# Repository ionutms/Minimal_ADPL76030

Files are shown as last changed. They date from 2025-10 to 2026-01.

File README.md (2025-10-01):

# Minimal_ADPL76030

## Overview

This repository contains a minimal KiCad design project for the Analog Devices ADPL76030, a synchronous 4-switch buck-boost DC/DC controller. The project includes schematic designs and PCB layout files for implementing this versatile power supply controller.

## Disclaimer

> [!NOTE]
> This project is provided "as is" and without any warranty, express or implied. For more details, please see the [LICENSE](LICENSE) file.

## About the ADPL76030

The ADPL76030 from Analog Devices is a high-efficiency synchronous 4-switch buck-boost DC-to-DC controller. It can regulate output voltage and current from an input voltage that can be above, below, or equal to the output voltage.

Key features include:

- **Wide Input Voltage Range:** 4V to 55V.
- **High Efficiency:** Up to 95% at 1.4 MHz.
- **Spread Spectrum Frequency Modulation:** For low EMI.
- **Fault Protection:** Includes various protection features.
- **Current Monitoring:** Provides current monitoring capabilities.
- **Package:** Available in a 28-lead LFCSP package.

## Project Structure

```
minimal_adpl76030/
├── minimal_adpl76030.kicad_pro       # Project configuration file
├── minimal_adpl76030.kicad_sch       # Main schematic file
├── minimal_adpl76030.kicad_pcb       # PCB layout file
├── fp-lib-table                    # Footprint library table
├── sym-lib-table                   # Symbol library table
├── docs/                           # Documentation files
│   ├── bom/                        # Bill of Materials
│   │   └── minimal_adpl76030_ibom.html # Interactive BOM file
│   ├── pictures/                   # Images and photos
│   │   ├── 1_minimal_adpl76030_side.png
│   │   ├── 2_minimal_adpl76030_top.png
│   │   ├── 3_minimal_adpl76030_bottom.png
│   │   ├── 4_minimal_adpl76030_left.png
│   │   └── 5_minimal_adpl76030_right.png
│   └── schematics/                 # Schematic PDF exports
│       └── minimal_adpl76030_schematics.pdf
└── KiCAD_Symbols_Generator/        # Submodule for symbol generation from CSV data
```

## Project Features

This design provides a minimal implementation of the ADPL76030 with:

- Proper power supply connections
- Buck-boost functionality
- Standard footprint for the 28-pin LFCSP package

## Getting Started

### Prerequisites

- [KiCad EDA](https://www.kicad.org/) version 9.0 or later installed on your system
- Git (for cloning the repository and submodule management)

### Opening the Project

1. **Clone the repository** (including submodules):
   ```bash
   git clone --recursive https://github.com/ionutms/Minimal_ADPL76030.git
   ```
   
   If you've already cloned the repository without submodules, initialize them with:
   ```bash
   git submodule init
   git submodule update
   ```

2. **Open the project in KiCad**:
   - Launch KiCad
   - Click "Open Existing Project"
   - Navigate to the cloned repository folder
   - Select the `minimal_adpl76030.kicad_pro` file

3. **Explore the design**:
   - Open the schematic editor to view the circuit design
   - Open the PCB editor to view the board layout
   - Review the symbol and footprint libraries used in the design

### Project Files

- **Main schematic**: `minimal_adpl76030.kicad_sch` - Contains the primary circuit design with the ADPL76030 and support components
- **PCB layout**: `minimal_adpl76030.kicad_pcb` - Physical board design file with proper component placement
- **Project configuration**: `minimal_adpl76030.kicad_pro` - KiCad project settings

## Dependencies

This project has the following dependencies:

### 1. KiCAD Symbols Generator

This repository uses [KiCAD_Symbols_Generator](https://github.com/ionutms/KiCAD_Symbols_Generator) as a submodule for custom symbol generation.

To initialize the submodule after cloning this repository:

```bash
git submodule update --init --recursive
```

### 2. 3D Models

This project requires the [3D_Models_Vault](https://github.com/ionutms/3D_Models_Vault) repository for 3D models.

#### Setup for KiCAD 9:

1. Clone the 3D models repository:
   ```bash
   git clone https://github.com/ionutms/3D_Models_Vault.git
   ```

2. In KiCAD 9, add an environment variable:
   - Variable name: `KICAD9_3D_MODELS_VAULT`
   - Variable value: Full path to where you cloned the 3D_Models_Vault repository

## Usage

After setting up the dependencies, open the project in KiCad 9 to access all features including the 3D models.

## Symbol Generator Submodule

This project includes the KiCAD_Symbols_Generator as a submodule, which provides tools for generating KiCad symbols from CSV data files. For more information on using this tool, see the [KiCAD_Symbols_Generator documentation](minimal_adpl76030/KiCAD_Symbols_Generator/README.md).

## Documentation

The `docs` folder contains:
- Schematic PDF exports
- Images and photos of the design

## Visuals

The following images showcase the PCB design from different perspectives:

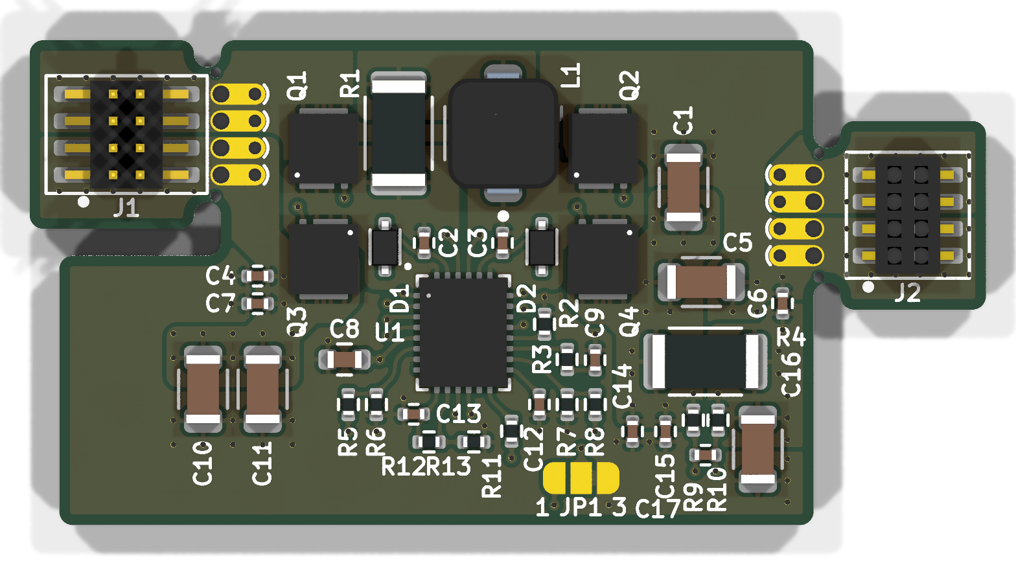
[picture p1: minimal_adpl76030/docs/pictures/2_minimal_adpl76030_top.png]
Top View

*Top View of the PCB*

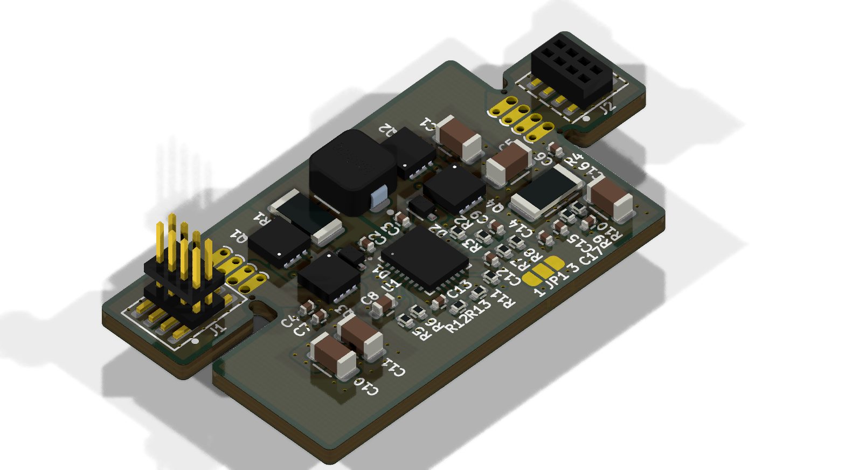
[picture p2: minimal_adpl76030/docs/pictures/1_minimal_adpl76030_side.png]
Side View

*Side View of the PCB*

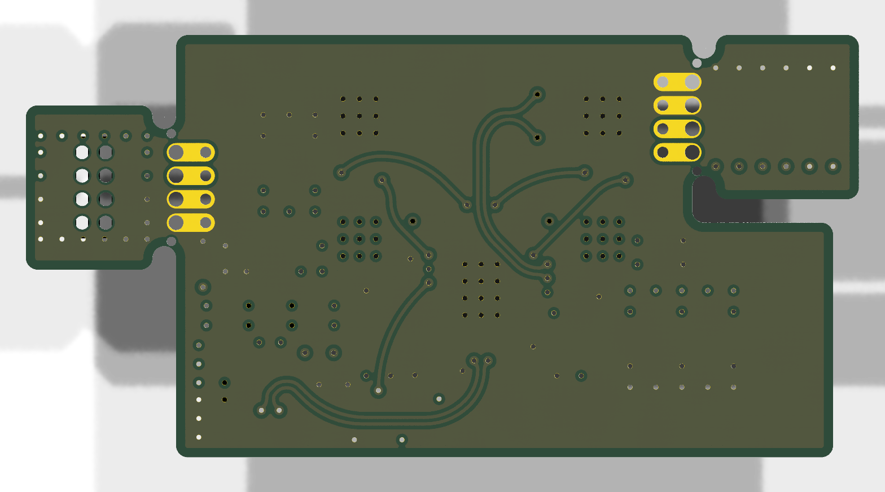
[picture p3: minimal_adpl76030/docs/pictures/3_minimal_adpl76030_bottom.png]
Bottom View

*Bottom View of the PCB*

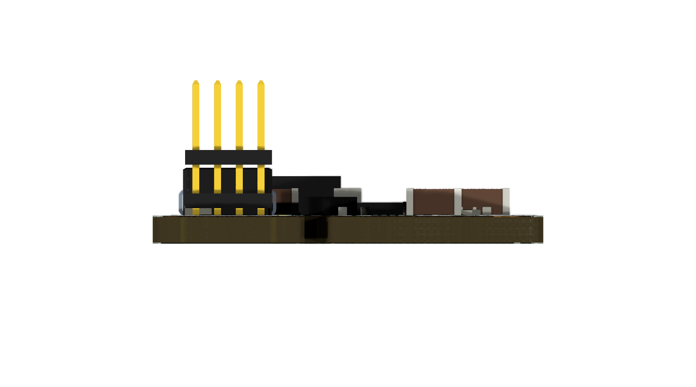
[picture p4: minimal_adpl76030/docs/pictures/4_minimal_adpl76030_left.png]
Left View

*Left View of the PCB*

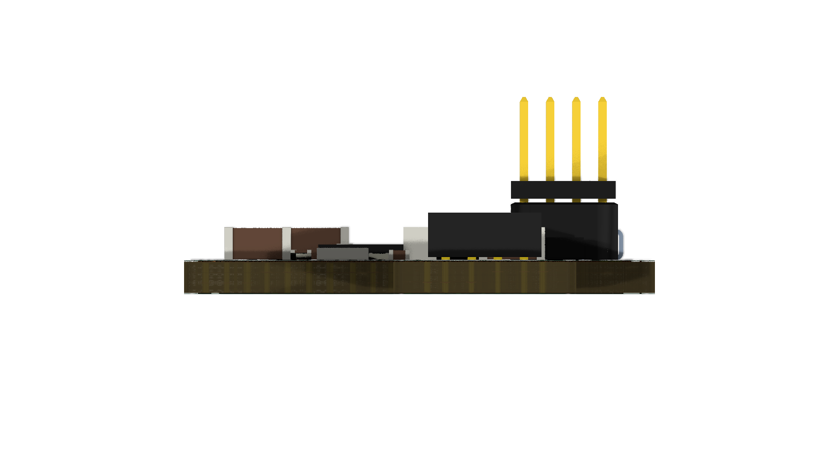
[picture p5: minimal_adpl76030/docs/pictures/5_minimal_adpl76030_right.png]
Right View

*Right View of the PCB*

## License

This project is licensed under the MIT License - see the [LICENSE](LICENSE) file for details.

## References

- [ADPL76030 Datasheet](https://www.analog.com/media/en/technical-documentation/data-sheets/adpl76030.pdf)
- [KiCad EDA](https://www.kicad.org/)

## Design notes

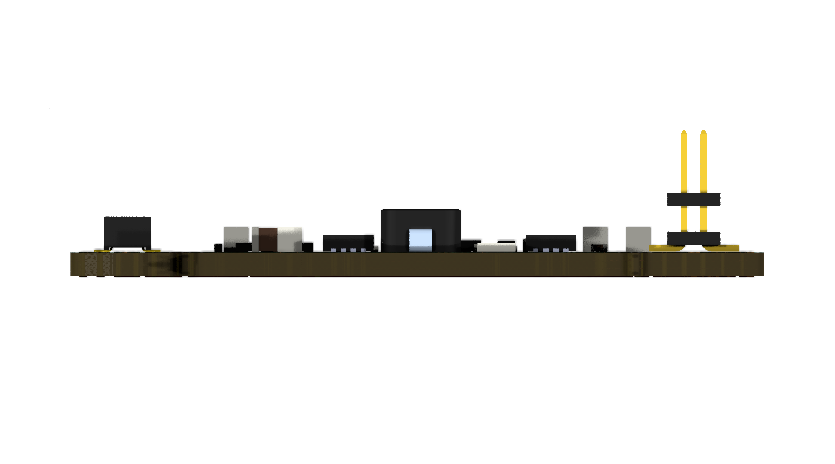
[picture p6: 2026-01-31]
minimal_adpl76030/docs/pictures/7_minimal_adpl76030_back.png

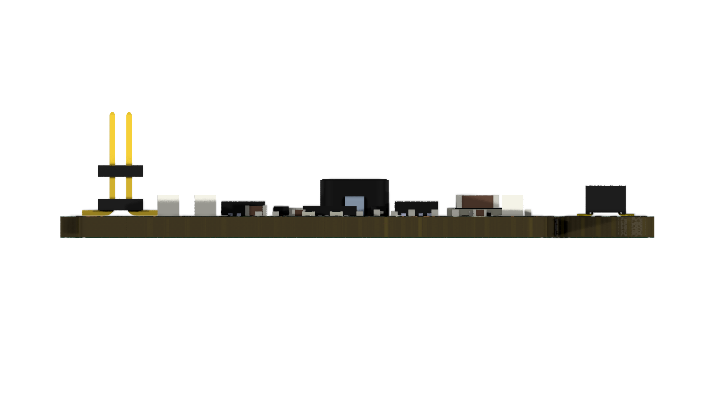
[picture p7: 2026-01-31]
minimal_adpl76030/docs/pictures/6_minimal_adpl76030_front.png

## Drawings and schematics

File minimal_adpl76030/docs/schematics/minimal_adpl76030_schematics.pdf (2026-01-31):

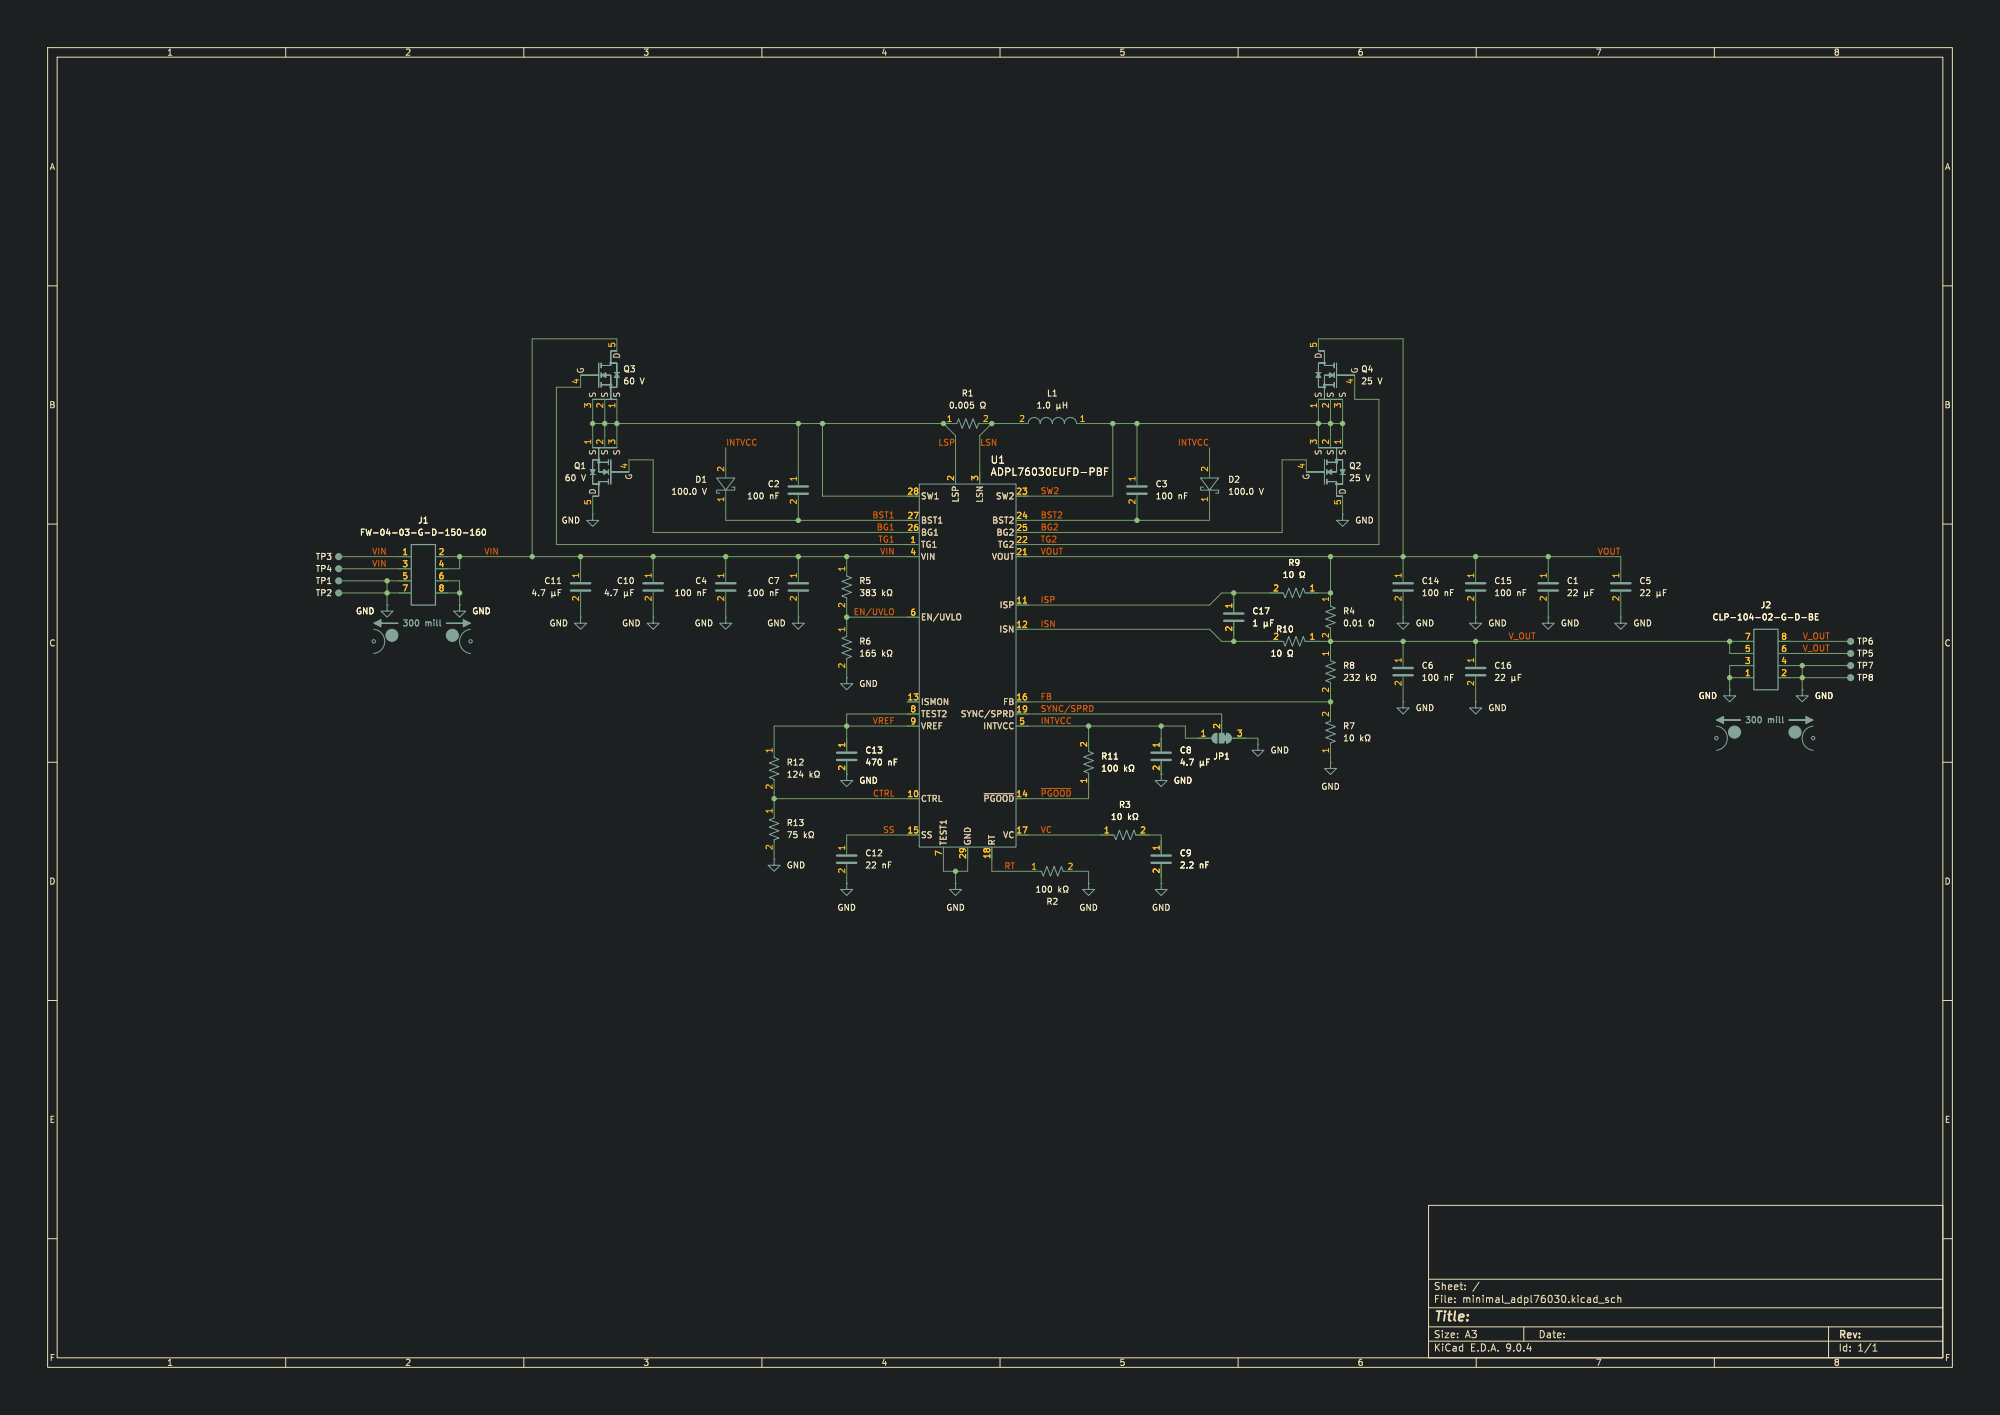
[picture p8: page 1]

INTVCC 5 VC 17 ~{PGOOD} 14 U1ADPL76030EUFD-PBF

ISN 12 FB 16 SYNC/SPRD 19

Id: 1/1 Title: File: minimal_adpl76030.kicad_sch Sheet: /

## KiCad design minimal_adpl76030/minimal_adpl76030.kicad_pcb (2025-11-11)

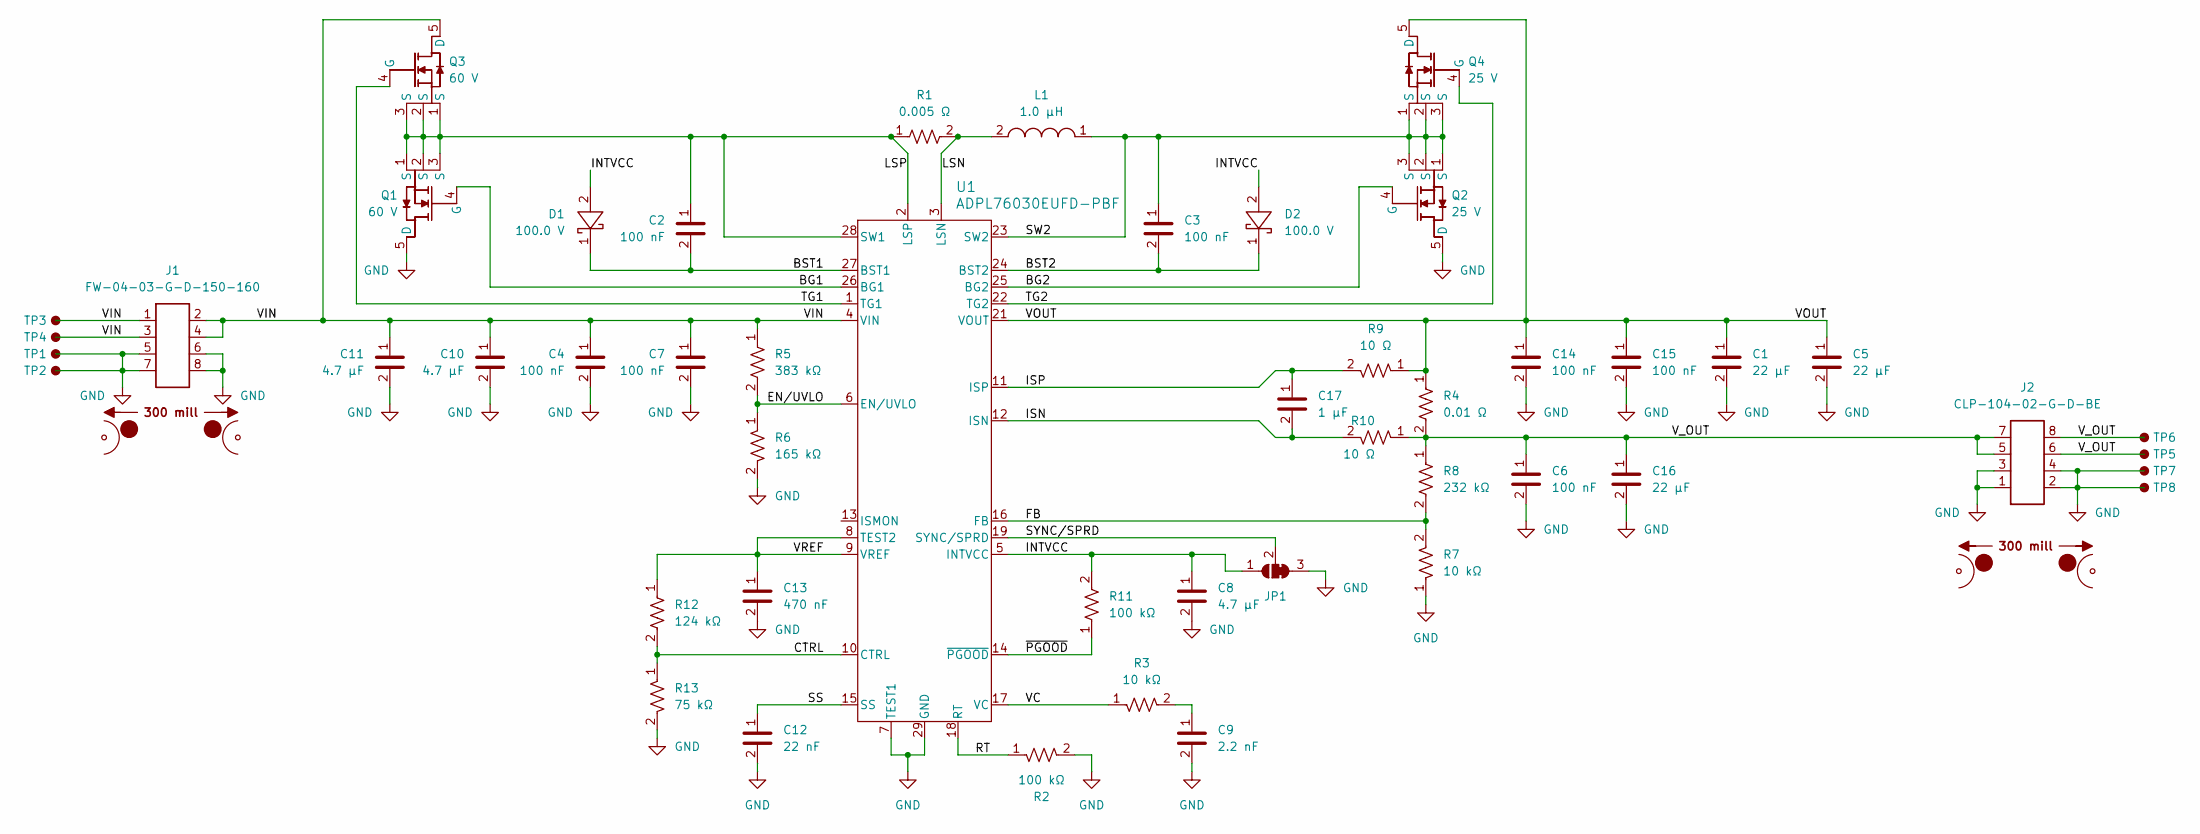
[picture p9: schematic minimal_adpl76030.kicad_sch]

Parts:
C1, C5, C16: 22 µF; C_1206_3216Metric; Tolerance 10%; Voltage Rating 25V; MPN CL31A226KAHNNNE
C2, C3, C4, C6, C7, C14, C15: 100 nF; C_0402_1005Metric; Tolerance 10%; Voltage Rating 50V; MPN GCM155R71H104KE02D
C8: 4.7 µF; C_0603_1608Metric; Tolerance 10%; Voltage Rating 10V; MPN GRM188C71A475KE11D
C9: 2.2 nF; C_0402_1005Metric; Tolerance 10%; Voltage Rating 50V; MPN GCM155R71H222KA37D
C10, C11: 4.7 µF; C_1206_3216Metric; Tolerance 10%; Voltage Rating 50V; MPN CL31B475KBHNNN#
C12: 22 nF; C_0402_1005Metric; Tolerance 10%; Voltage Rating 50V; MPN GCM155R71H223KA55D
C13: 470 nF; C_0402_1005Metric; Tolerance 10%; Voltage Rating 10V; MPN GCM155C71A474KE36D
C17: 1 µF; C_0402_1005Metric; Tolerance 10%; Voltage Rating 16V; MPN C1005X6S1C105K050BC
D1, D2: 100.0 V; SOD323F; MPN BAT46WJ,115
J1: FW-04-03-G-D-150-160; Current Rating (A) 5.2; Voltage Rating (V) 300; MPN FW-04-03-G-D-150-160
J2: CLP-104-02-G-D-BE; Current Rating (A) 5.2; Voltage Rating (V) 300; MPN CLP-104-02-G-D-BE
JP1: SolderJumper_3_Open; SolderJumper-3_P1.3mm_Bridged_2_3_RoundedPad1.0x1.5mm_Numbe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
L1: 1.0 µH; 74437336; Tolerance ±20%; MPN 74437336010
MB1, MB2: mouse-bite-50mil-300mil
Q1, Q3: 60 V; TSDSON-8FL; MPN BSZ065N06LS5ATMA1
Q2, Q4: 25 V; TSDSON-8FL; MPN BSZ031NE2LS5ATMA1
R1: 0.005 Ω; R_2010_5025Metric; Tolerance 1%; MPN CRF2010-FZ-R005ELF
R2, R11: 100 kΩ; R_0402_1005Metric; Tolerance 1%; Voltage Rating 50V; MPN ERJ-2RKF1003X
R3, R7: 10 kΩ; R_0402_1005Metric; Tolerance 1%; Voltage Rating 50V; MPN ERJ-2RKF1002X
R4: 0.01 Ω; R_2010_5025Metric; Tolerance 1%; MPN CRF2010-FZ-R010ELF
R5: 383 kΩ; R_0402_1005Metric; Tolerance 1%; Voltage Rating 50V; MPN ERJ-2RKF3833X
R6: 165 kΩ; R_0402_1005Metric; Tolerance 1%; Voltage Rating 50V; MPN ERJ-2RKF1653X
R8: 232 kΩ; R_0402_1005Metric; Tolerance 1%; Voltage Rating 50V; MPN ERJ-2RKF2323X
R9, R10: 10 Ω; R_0402_1005Metric; Tolerance 1%; Voltage Rating 50V; MPN ERJ-2RKF10R0X
R12: 124 kΩ; R_0402_1005Metric; Tolerance 1%; Voltage Rating 50V; MPN ERJ-2RKF1243X
R13: 75 kΩ; R_0402_1005Metric; Tolerance 1%; Voltage Rating 50V; MPN ERJ-2RKF7502X
TP1, TP2, TP3, TP4, TP5, TP6, TP7, TP8: TestPoint; TestPoint_THTPad_Castelated
U1: ADPL76030EUFD-PBF; UFD_05-08-1712_ADI; MPN ADPL76030EUFD-PBF

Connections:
/BG1: Q1.4 (G), U1.26 (BG1)
/BG2: Q2.4 (G), U1.25 (BG2)
/BST1: C2.2, D1.1, U1.27 (BST1)
/BST2: C3.2, D2.1, U1.24 (BST2)
/CTRL: R12.2, R13.1, U1.10 (CTRL)
/EN/UVLO: R5.2, R6.1, U1.6 (EN/UVLO)
/FB: R7.2, R8.2, U1.16 (FB)
/INTVCC: C8.1, D1.2, D2.2, JP1.1 (A), R11.2, U1.5 (INTVCC)
/ISN: C17.2, R10.2, U1.12 (ISN)
/ISP: C17.1, R9.2, U1.11 (ISP)
/LSN: L1.2, R1.2, U1.3 (LSN)
/LSP: C2.1, Q1.1 (S), Q1.2 (S), Q1.3 (S), Q3.1 (S), Q3.2 (S), Q3.3 (S), R1.1, U1.2 (LSP), U1.28 (SW1)
/RT: R2.1, U1.18 (RT)
/SS: C12.1, U1.15 (SS)
/SW2: C3.1, L1.1, Q2.1 (S), Q2.2 (S), Q2.3 (S), Q4.1 (S), Q4.2 (S), Q4.3 (S), U1.23 (SW2)
/SYNC/SPRD: JP1.2 (C), U1.19 (SYNC/SPRD)
/TG1: Q3.4 (G), U1.1 (TG1)
/TG2: Q4.4 (G), U1.22 (TG2)
/VC: R3.1, U1.17 (VC)
/VIN: C4.1, C7.1, C10.1, C11.1, J1.1, J1.2, J1.3, J1.4, Q3.5 (D), R5.1, TP3.1, TP4.1, U1.4 (VIN)
/VOUT: C1.1, C5.1, C14.1, C15.1, Q4.5 (D), R4.1, R9.1, U1.21 (VOUT)
/VREF: C13.1, R12.1, U1.8 (TEST2), U1.9 (VREF)
/V_OUT: C6.1, C16.1, J2.5, J2.6, J2.7, J2.8, R4.2, R8.1, R10.1, TP5.1, TP6.1
/~PGOOD: R11.1, U1.14 (~PGOOD)
GND: C1.2, C4.2, C5.2, C6.2, C7.2, C8.2, C9.2, C10.2, C11.2, C12.2, C13.2, C14.2, C15.2, C16.2, J1.5, J1.6, J1.7, J1.8, J2.1, J2.2, J2.3, J2.4, JP1.3 (B), Q1.5 (D), Q2.5 (D), R2.2, R6.2, R7.1, R13.2, TP1.1, TP2.1, TP7.1, TP8.1, U1.7 (TEST1), U1.29 (GND)
unnamed: C9.1, R3.2

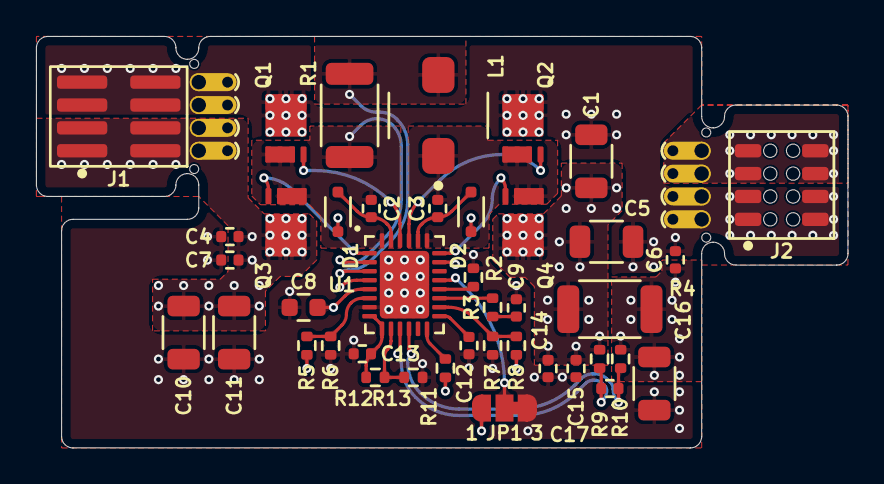
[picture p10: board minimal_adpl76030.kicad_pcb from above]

Board: 4 copper layers, 45.1 x 22.9 mm, 51 parts (0 on the bottom side), 26 nets.

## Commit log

2025-09-28 Set up KiCAD project with initial schematic, PCB, and GitHub workflows
    [minimal_adpl76030.kicad_pcb, minimal_adpl76030.kicad_sch]
2025-09-28 Update KiCad documentation for minimal_adpl76030 (schematics and PCB renders)
2025-10-01 Update zoom factors in kicad-config.yml
2025-10-01 Update zoom factors and side view pan in kicad-config.yml
2025-10-04 Update KiCAD configuration
2025-10-05 chore: update workflows and kicad config from central repository
2025-10-26 Update kicad-config.yml to adjust zoom and pan for better views
